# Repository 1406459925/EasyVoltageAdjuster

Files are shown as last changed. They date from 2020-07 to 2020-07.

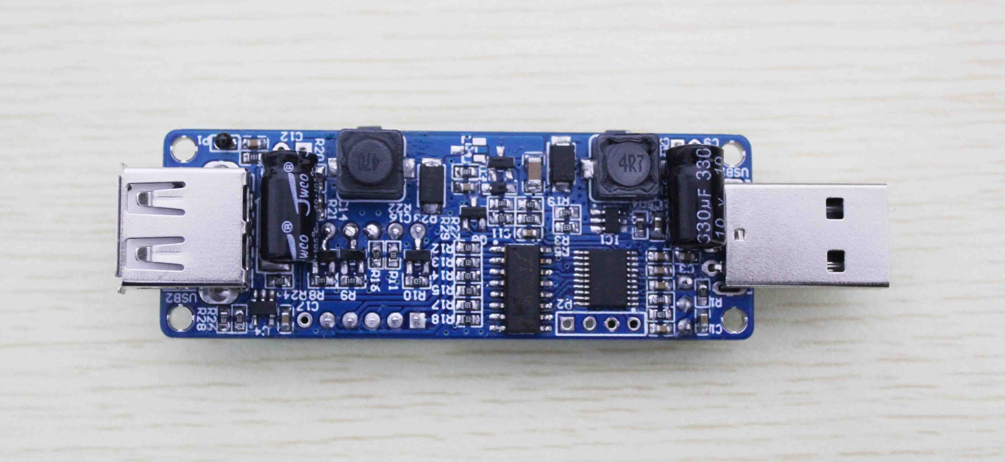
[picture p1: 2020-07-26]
Picture/背面.JPG

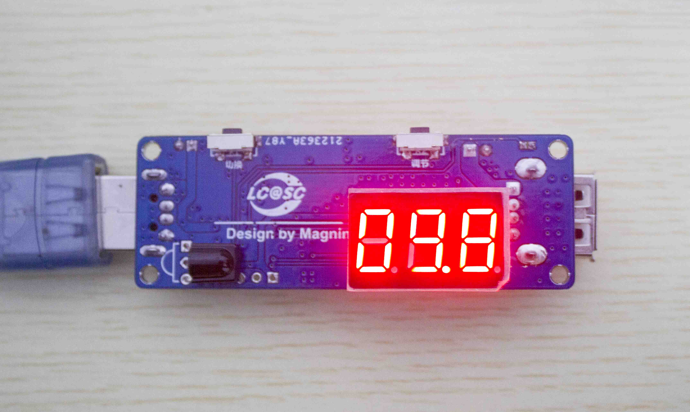
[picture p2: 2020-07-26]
Picture/显示.jpg

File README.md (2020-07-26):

# EasyVoltageAdjuster
简单USB调压器，三位数码管显示，支持恒流恒压调整模式模式、红外遥控与按键调节、温度显示。
## 硬件构成

## 参数
	电压输出范围：3.0 - 12V
	电流输出范围：0 - 900MA
	最大功率：5 W
## 功能
* 低成本
* 5V USB供电，可用充电宝供电，支持3.3V到12V直流输出。
* PID调节，支持恒压、恒流模式。
* 软件缓启动、过流、过压保护。
* 当前室内温度显示。
* 采用3位数码管可显示电流、电压、温度等。
* 支持在机身的轻触按键及红外遥控配置电压电流等参数。
## 文件夹说明

* HardWare：硬件工程文件夹（Altium Designer）
* SoftWare：软件工程文件夹（IAR for STM8）
* Picture：展示图片

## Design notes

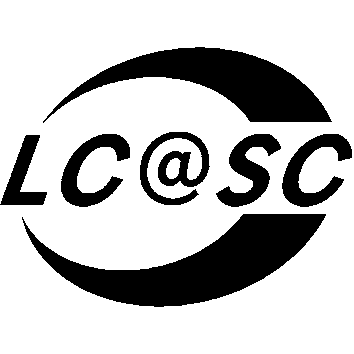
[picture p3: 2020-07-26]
Picture/未标题-2.bmp

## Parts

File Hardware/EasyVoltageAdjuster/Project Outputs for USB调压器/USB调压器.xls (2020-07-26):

Comment | Description | Designator | Footprint | Quantity
100nF | 贴片电容 | C1, C4, C7, C9, C10, C11, C13, C16 | LC-0603_C | 8
1uF | 贴片电容 | C2, C8, C15 | LC-0603_C | 3
10uF | 贴片电容 | C3 | LC-0603_C | 1
22uF | 贴片电容 | C5 | LC-0805_C | 1
10uF | 贴片电容 | C6 | LC-1206_C | 1
100uF/35V | 直插电解电容 | C12 | CAP 2.5*6.3*11.2-H | 1
20pF | 贴片电容 | C14 | LC-0603_C | 1
SS34 | 二极管 | D1, D2 | LC-SMA(DO-214AC)_S1 | 2
1N4007 | 开关二极管 | D3 | SOD-323 | 1
ZMM10 | 稳压二极管 | D4 | LC-LL-34 | 1
MF-NSMF020-2 0.2A 24V | 自恢复保险丝 | F1 | 1206 | 1
VS1838B | 红外接收头 | HR1 | VS1838B-A | 1
SX1308 | 可调升压芯片 | IC1 | SOT23-6N | 1
SW_P | 轻触开关侧 | K1, K2 | KEY-TH_K2-1112SA-AXXW-XX | 2
10uH | 功率屏蔽电感 | L1 | CDRH73 | 1
47uH | 功率屏蔽电感 | L2 | CDRH73 | 1
Header 2 | 接插件 | P1 | 1.27mm*2_via | 1
Header 4P |  | P2 | 2.54mm_4P | 1
SS8550 Y2 | 三极管 | Q1, Q2, Q3 | LC-SOT-23(SOT-23-3) | 3
AO3407 P道沟 X13A15 SOT-23 | MOS(场效应管) | Q4 | LC-SOT-23(SOT-23-3) | 1
SS8050 Y1 | 三极管 | Q5, Q6 | LC-SOT-23(SOT-23-3) | 2
100KΩ | 贴片电阻 | R1, R4, R20, R25, R28 | LC-0603_R | 5
10KΩ | 贴片电阻 | R2, R5, R6, R7, R8, R9, R10, R21, R22, R23, R24, R29 | LC-0603_R | 12
390KΩ | 贴片电阻 | R3 | LC-0603_R | 1
330Ω | 贴片电阻 | R11, R12, R13, R14, R15, R16, R17, R18 | LC-0603_R | 8
4.7KΩ | 贴片电阻 | R19 | LC-0603_R | 1
1KΩ | 贴片电阻 | R26 | LC-0603_R | 1
0.1Ω | 贴片电阻 | R27 | R 2512_L | 1
3631B | 0.36寸3位共阳数码管 | SMG1 | SMG 0.36-3P | 1
ME6209 | 低压差线性稳压 | U1 | LC-SOT-23(SOT-23-3) - duplicate | 1
STM8S003F3P6 | MCU | U2 | LC-TSSOP-20 | 1
74HC595D | 74系列逻辑芯片 | U3 | LC-SOIC-16_150mil | 1
LMV321IDBVRG4 | 运放 | U4 | LC-SOT-23-5 | 1
USB | USB-A型公接口 | USB1 | USB_A/P_A | 1
USB | USB-A型母接口 | USB2 | USB-A/S_A | 1

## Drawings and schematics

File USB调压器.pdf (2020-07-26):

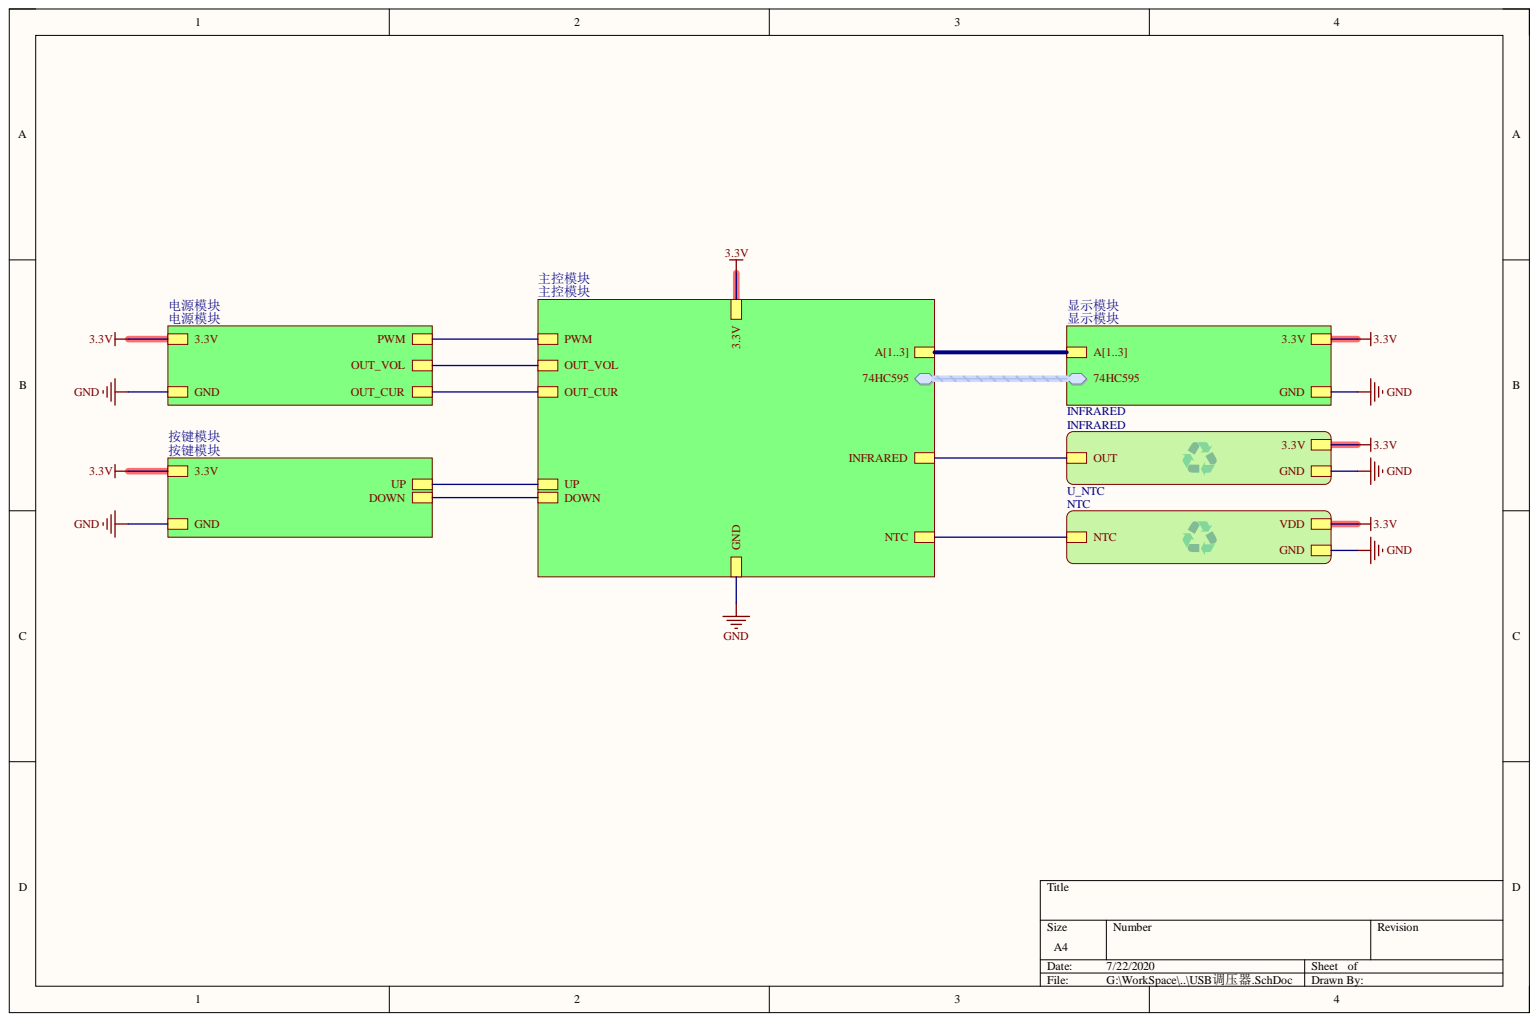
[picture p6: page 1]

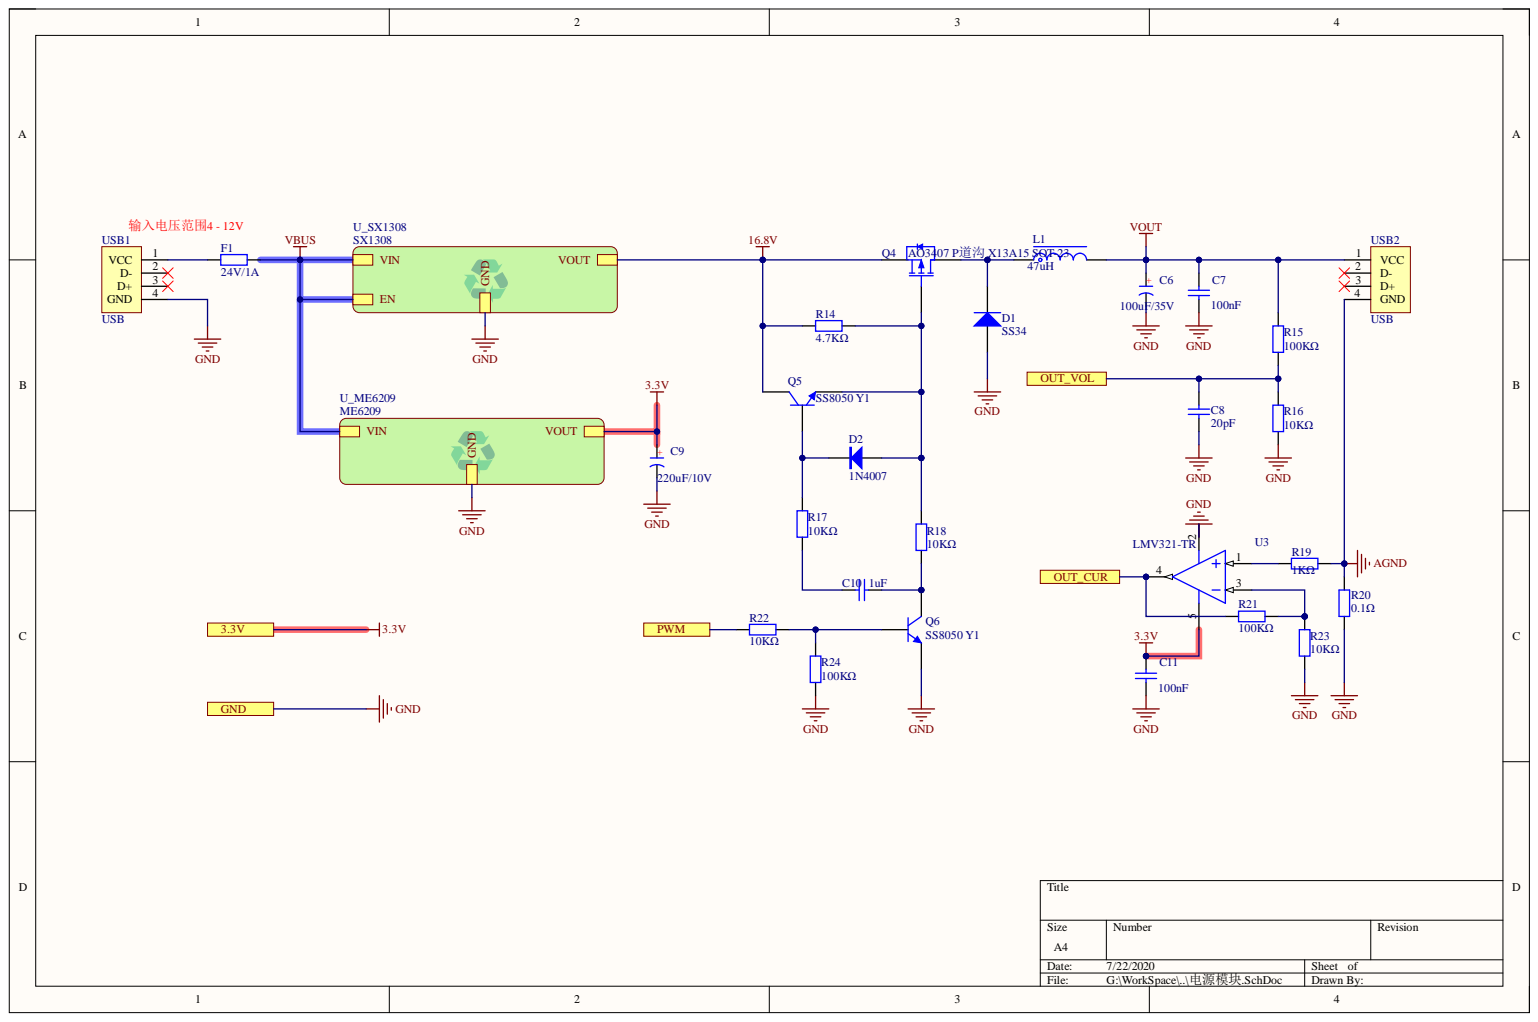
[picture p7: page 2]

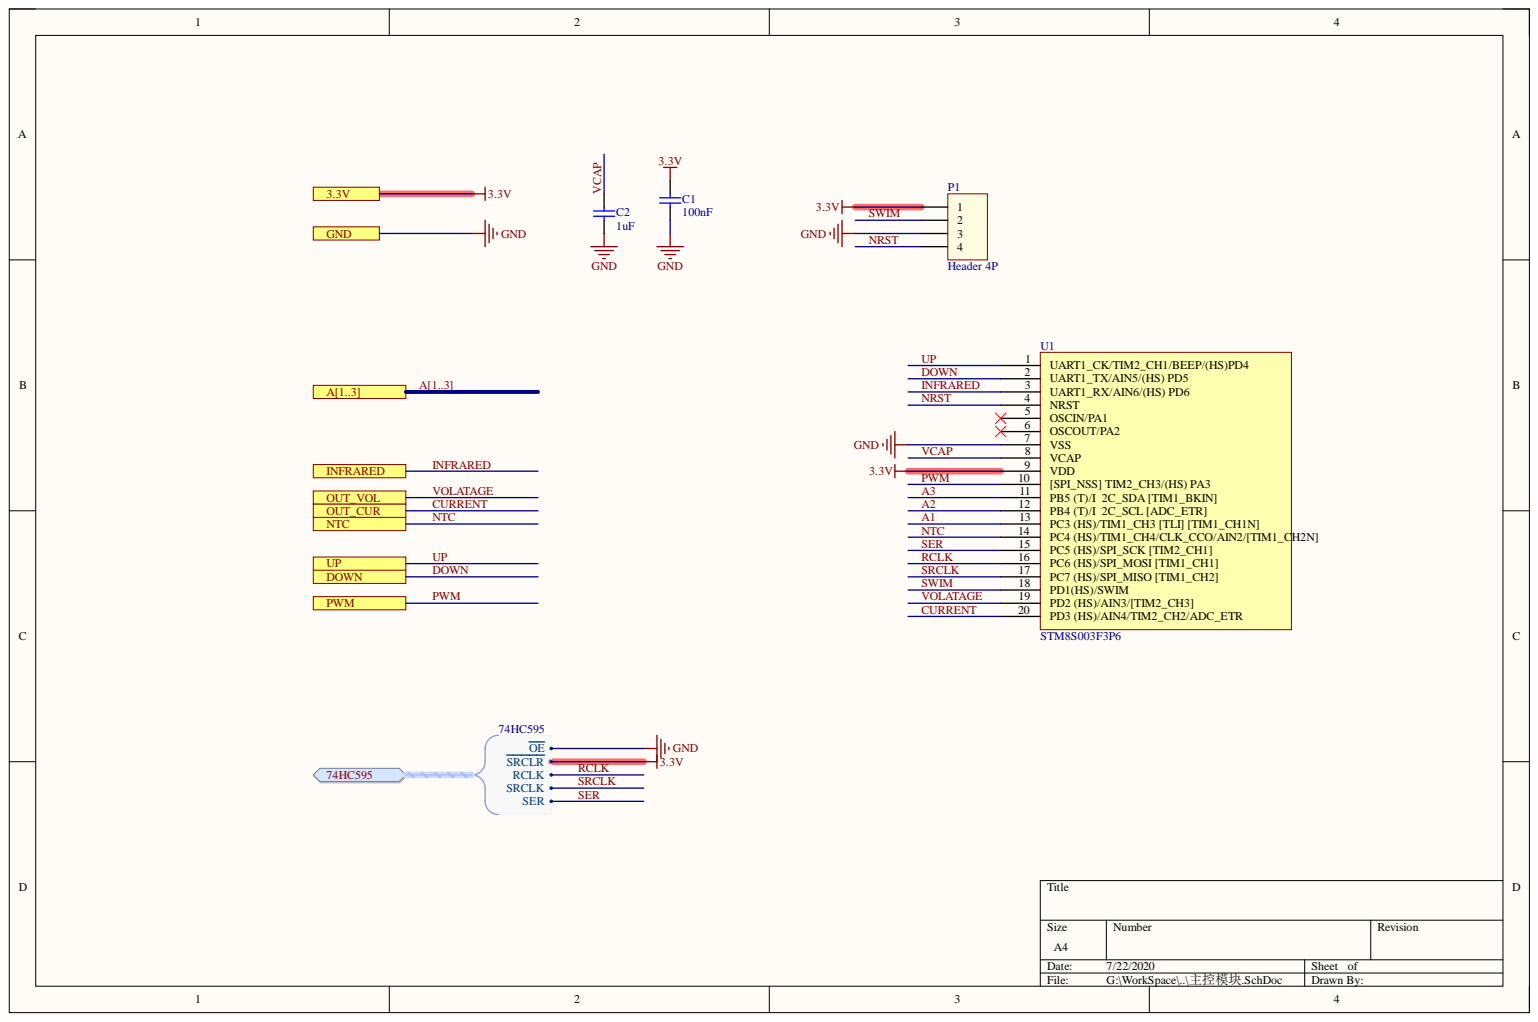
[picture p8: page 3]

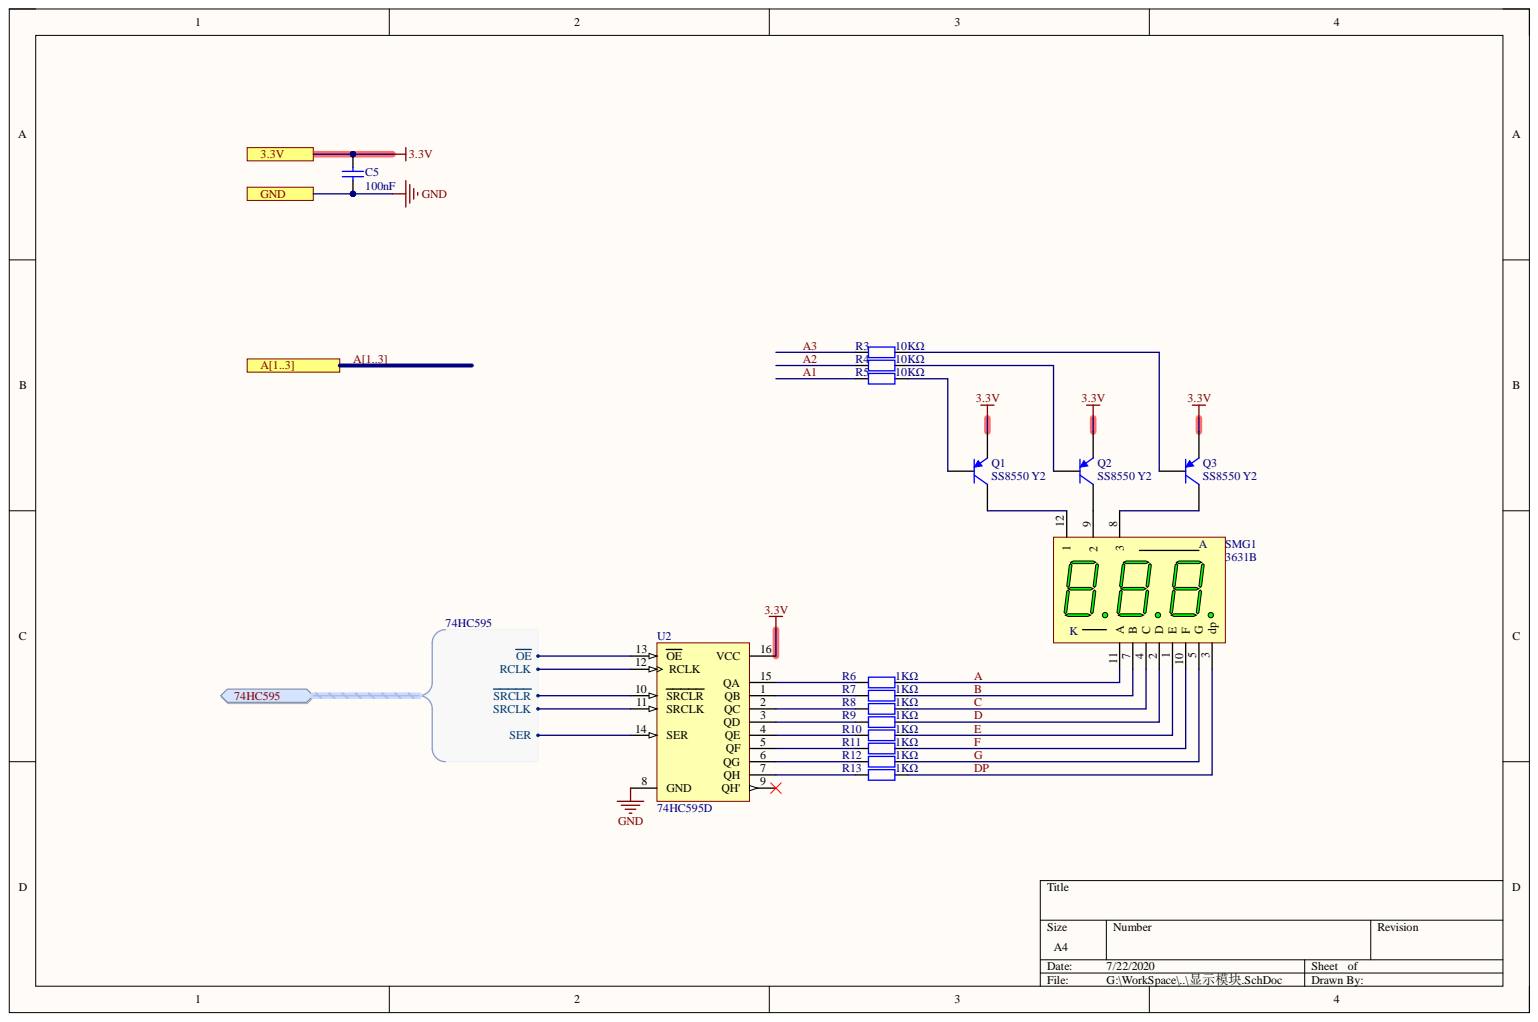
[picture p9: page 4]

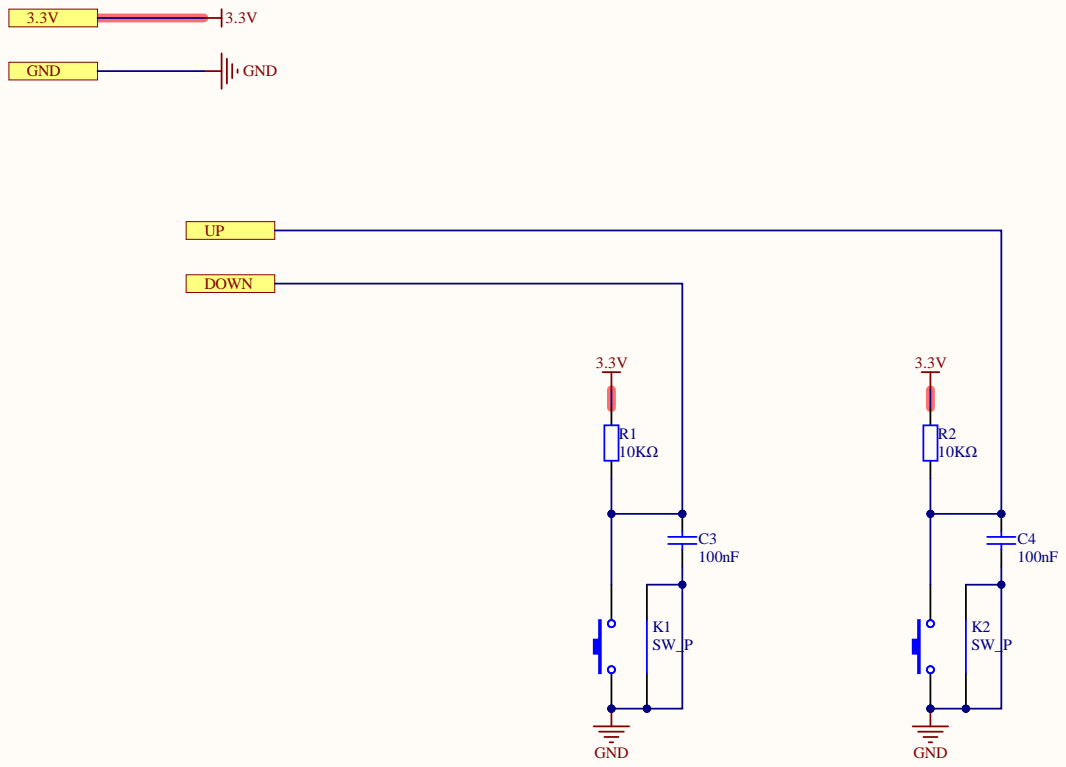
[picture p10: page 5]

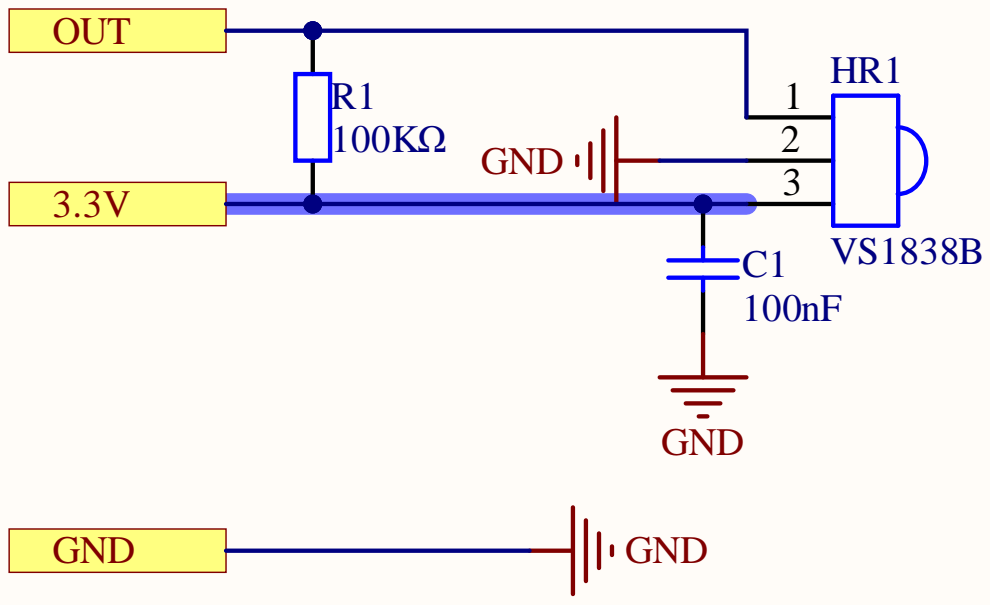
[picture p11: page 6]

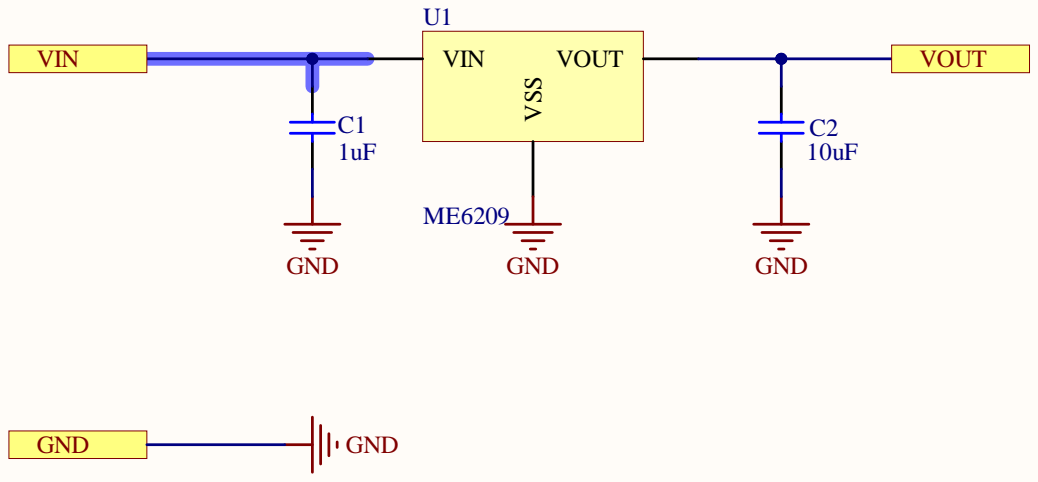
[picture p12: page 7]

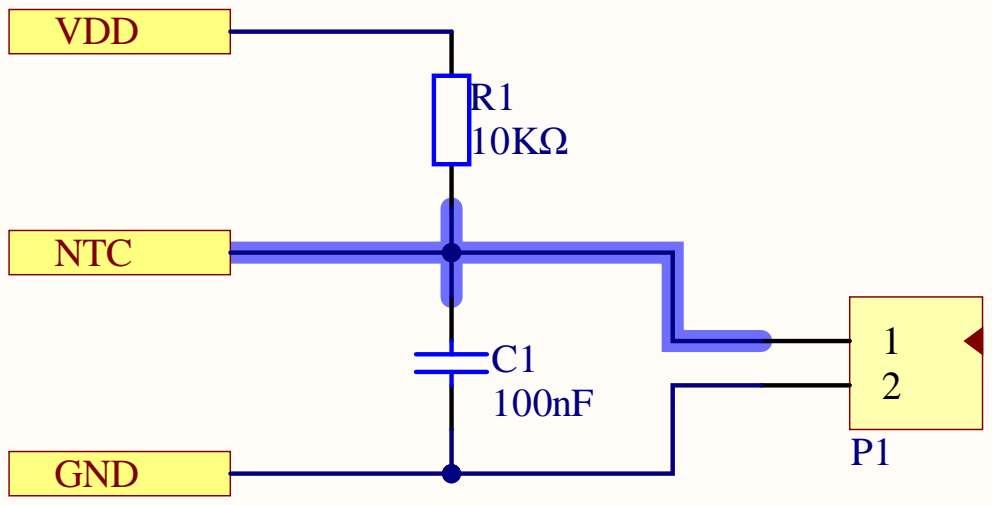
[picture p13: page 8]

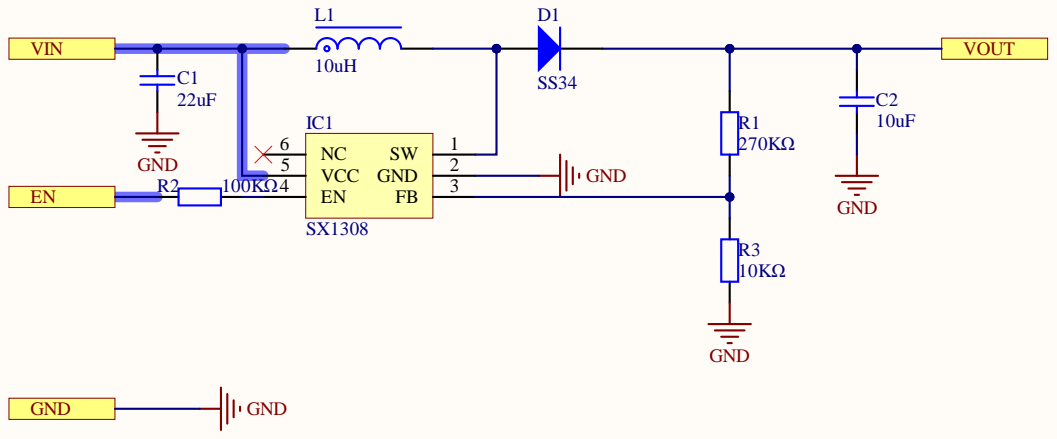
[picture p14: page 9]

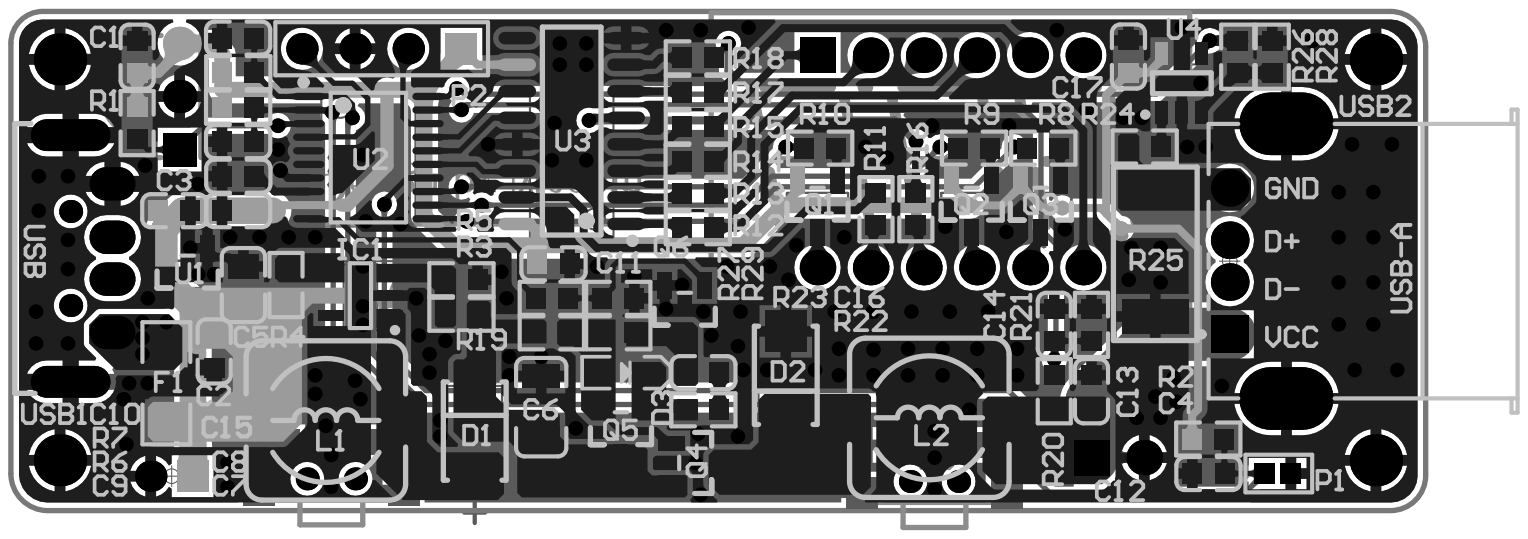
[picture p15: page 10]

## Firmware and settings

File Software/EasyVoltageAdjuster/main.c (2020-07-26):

/*****************************************************
******************USB 调压器 V1.0*********************
描述：仅供学习交流之用，请勿用作商业用途
作者：MAGNIN
版本：V1.0
日志：
2020/06/15 MAGNIN 创建工程
*****************************************************/
#include <iostm8s003f3.h>
#include "intrinsics.h"
#include "tim.h"
#include "adc.h"
#include "menu.h"
#include "share.h"
#include "display.h"
#include "infrared.h"
#include "controller.h"
#include "eeprom.h"
#include "temp.h"

//#define INFRARED_CODE_MEANSURE     //红外码测量   

#define ANALOG_COLLECT_CNT     20  //采集模拟量时间
#define DISPLAY_REFRESH_CNT    40  //显示刷新时间
//初始化时钟
static void Clock_Init(void)
{
  CLK_SWCR_SWIEM = 1;               //开启时钟切换
  CLK_SWR = 0xE1;                   //设置目标时钟源
  while(!MASK_CLK_SWCR_SWIF);       //等待时钟切换完成
  CLK_SWCR &= ~MASK_CLK_SWCR_SWIF;  //清除状态位
  CLK_SWCR_SWEN = 1;                //切换时钟
  CLK_CKDIVR = 0x00;                //设置时钟频率为16MHZ
}
//采集模拟量
static void CollectAnalog(void)
{
  static uint8_t cnt;
  switch(cnt++)
  {
  case 1:
    ADC_INxOpen(CHANNEL_VOLTAGE);
    break;
  case 2:
    ADC_INxConversion(CHANNEL_VOLTAGE);
    ADC_INxOpen(CHANNEL_CURRENT);
    break;
  case 3:
    ADC_INxConversion(CHANNEL_CURRENT);
    ADC_INxOpen(CHANNEL_TEMPERATURE);
    break;
  case 4:
    ADC_INxConversion(CHANNEL_TEMPERATURE);
    break;
  case ANALOG_COLLECT_CNT:
    cnt = 0;
    break;
  default:break;
  }
}
//程序入口
int main( void )
{
  uint16_t i = 0;
  enum EnumCurrentPage page;
  Clock_Init();
  ADC_Init();
  PWM_Init();
  KEY_Init();
  Display_Init();
  Infrared_Init();
  Controller_Init();
  Menu_Init();
  Display_Logo();
  //Delay_Ms(1000);
  PWM_SetDutyCycle(1);
   __enable_interrupt();
  while(1)
  { 
    if(i % 60 == 0)
    {
      TypeEnumKey key = KEY_Scan(); 
      uint8_t inf = Infrared_GetValue();
#ifdef INFRARED_CODE_MEANSURE
      if(inf) Display_WriteValue(0,inf,0);      //红外编码检测
#else
       switch(inf)
      {
      case INFRARED_KEY_MODE:
        key =   KEY_SET;
        break;
      case INFRARED_KEY_CHANGE:
        key =   KEY_CHANGE;
        break;
      case INFRARED_KEY_UP:
        key =  KEY_UP; 
        break;
      case INFRARED_KEY_DOWN:
        key = KEY_DOWN;
        break;
      case  INFRARED_KEY_POWER:
        key = KEY_POWER;
        break;
      default:break;
      }
      page = Menu(key); 
#endif
    } 
#ifndef INFRARED_CODE_MEANSURE
    if(i % 6000 == 0)
    {
       uint16_t value;
       switch(page)
      {
      case CURRENT_VOLTAGE:       //电压显示    0.0V   - 99.9V（显示精度0.1V）
        value = (uint16_t)((float)ADC_GetValue(CHANNEL_VOLTAGE)*10*VOLTAGE_MACRO);
        Display_WriteValue(0,value,1);
        break;
      case CURRENT_CURRENT:       //电流显示范围 0ma - 999ma（显示精度1ma）
        value = (uint16_t)((float)ADC_GetValue(CHANNEL_CURRENT)*CURRENT_MACRO);  //放大11倍
        Display_WriteValue(0,value,0);
        break;
      case  CURRENT_TEMPERATURE:  //温度显示范围 -99℃ - 99.9℃（显示精度-99℃ - -10℃ 内1℃精度，-9.9℃ - 99.9℃内0.1℃精度）
        value = (uint16_t)((float)ADC_GetValue(CHANNEL_TEMPERATURE)*1000*TEMPERATURE_MACRO);
        value = (uint16_t)Calculate_TemperatureValue(value);
        Display_WriteValue(0,(uint16_t)value,1);
        break;
      default:break;
      }
      i = 0;
    } 
#endif
    if(i % DISPLAY_REFRESH_CNT == 0)  Display_Refresh();
    CollectAnalog();
    Delay_Us(16);
    i++;
  }
}

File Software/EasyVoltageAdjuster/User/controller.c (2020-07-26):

/********************************************
文件描述：PID控制
作者：MAGNIN
日志：
2020/06/23 MAGNIN 建立文件

********************************************/
#include "controller.h"
#include "pid.h"
#include "adc.h"
#include "tim.h"

static TypeStructPid vPid;
static TypeStructPid iPid;

static enum EnumPid pidMode = PID_VOLTAGE;
//控制初始化
void Controller_Init(void)
{
  PID_Reset(&vPid);
  vPid.dt = 0.00002;
  vPid.kp = 0.5f;
  vPid.ki = 0.00004f;
  vPid.kd = 0.0f;
  vPid.target = 6.0f;	//V.默认稳压输出
  vPid.LimitMin = 1;
  vPid.LimitMax = 92;
  PID_Init(&vPid);
  
  PID_Reset(&iPid);
  iPid.dt = 0.00002;
  iPid.kp = 10.0f;
  iPid.ki = 0.00010f;
  iPid.kd = 0.0f;
  iPid.target = 0.1f;	//i.默认稳压输出
  iPid.LimitMin = 1;
  iPid.LimitMax = 92;
  PID_Init(&iPid);
  
  TIM1_Init(16,500,0);
}
//PID控制
void PID_Controller(void)
{
  float analog;
  TypePidState state;
  static uint16_t cnt;
  switch(pidMode)
  {
  case PID_VOLTAGE:
    analog = (float)ADC_GetValue(CHANNEL_VOLTAGE)*VOLTAGE_MACRO;
    analog += (float)ADC_GetValue(CHANNEL_CURRENT)*CURRENT_MACRO/10000;  //电流补偿
    PWM_SetDutyCycle((uint16_t)PID_Compute(&vPid,analog));
    break;
  case PID_CURRENT:
    analog = (float)ADC_GetValue(CHANNEL_CURRENT)*CURRENT_MACRO/1000;
    PWM_SetDutyCycle((uint16_t)PID_Compute(&iPid,analog));
    break;
  default:
    break;
  }
  state = PID_GetState();
  if(state == PID_SLOW_START) ++cnt;
  if(cnt > 2000) 
  {
    cnt = 0;
    PID_SetState(PID_NORMAL);
  }
}
//设置控制电压
void PID_SetVoltage(uint8_t voltage)
{
  vPid.target = (float)voltage/10;
}
//设置电流
void PID_SetCurrent(uint8_t currrent)
{
  iPid.target = (float)currrent/100;
}
//设置模式
void PID_SetMode( enum EnumPid mode)
{
  pidMode = mode;
  if(mode == PID_OFF) PWM_Off();
  else PWM_Open();
  
}
//获取模式
enum EnumPid PID_GetMode(void)
{
  return pidMode;
}
